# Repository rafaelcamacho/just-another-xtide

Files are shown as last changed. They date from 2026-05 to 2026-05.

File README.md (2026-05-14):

# Just Another XT-IDE

A collection of my XT-IDE PCB layout experiments and hardware variations
created for the retrocomputing community.

These boards are based on the original XT-IDE concepts and schematics from
GlitchWorks, with some PCB layout inspiration drawn from Monotech designs.

This repository provides:
- Gerber files
- Schematics
- Build notes and documentation

PCB source/layout files are intentionally not included.

Use at your risk.

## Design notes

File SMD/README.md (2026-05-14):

# SMD Just Another XT-IDE Boards

This directory contains SMD versions of the Just Another XT-IDE board designs.

The goal of these revisions is to provide:

- Routing fun.
- Low-cost final XT-IDE (...).

## Version Overview

| Version | Status | Notes |
|---|---|---|

## Design Philosophy

The SMD variants are intended for:

- Retro hardware experimentation.

## Notes

Each version directory contains:

- Gerber files.
- Bill of materials (BOM).
- Pick and Place file.
- Configuration documentation.

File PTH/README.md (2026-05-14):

# PTH Just Another XT-IDE Boards

This directory contains through-hole (PTH) versions of the Just Another XT-IDE board designs.

The goal of these revisions is to provide:

- Easy hand assembly.
- Component alignment.
- Switches access.
- Fix previous errors.

## Version Overview

| Version | Status | Notes |
|---|---|---|
| v0.4 | Prototype | Improved routing, mechanical adjustments and silkscreen |

## Design Philosophy

The PTH variants are intended for:

- Hobbyist assembly.
- Easier troubleshooting.
- Retro hardware experimentation.
- Low-cost PCB manufacturing.

## Notes

Each version directory contains:

- Gerber files.
- Bill of materials (BOM).
- Configuration documentation.

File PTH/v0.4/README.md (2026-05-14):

# Just Another XT-IDE PTH v0.4

## Documentation

| File | Description |
|---|---|
| SWITCHES.md | Jumper and switch configuration |
| BOM.md | Component list / Bill of Materials |

## Compatibility

Tested with:

- IBM XT compatible systems
- CompactFlash IDE adapters
- Standard IDE hard drives
- XTIDE Universal BIOS

## Notes

This board is intended for experimental and hobbyist retrocomputing use.

Some configurations may require BIOS changes depending on the target system.

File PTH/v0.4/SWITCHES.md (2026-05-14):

# Switch and Jumper Configuration

This document describes the configuration switches and jumpers available on the Just Another XT-IDE PTH v0.4 board.

---

## Switch Logic

| Value | State |
|---|---|
| 0 | OFF |
| 1 | ON |

---

# IDE Address

Default setting: `110000` (`0x300h`)

The IDE I/O base address is configured through switches 1 to 6.

| Switch | Address Bit |
|---|---|
| 1 | A9 |
| 2 | A8 |
| 3 | A7 |
| 4 | A6 |
| 5 | A5 |
| 6 | A4 |

---

## Address Table

| 1 | 2 | 3 | 4 | 5 | 6 | Address |
|---|---|---|---|---|---|---|
| 1 | 0 | 0 | 0 | 0 | 0 | 0200h |
| 1 | 0 | 0 | 0 | 0 | 1 | 0210h |
| 1 | 0 | 0 | 0 | 1 | 0 | 0220h |
| 1 | 0 | 0 | 0 | 1 | 1 | 0230h |
| 1 | 0 | 0 | 1 | 0 | 0 | 0240h |
| 1 | 0 | 0 | 1 | 0 | 1 | 0250h |
| 1 | 0 | 0 | 1 | 1 | 0 | 0260h |
| 1 | 0 | 0 | 1 | 1 | 1 | 0270h |
| 1 | 0 | 1 | 0 | 0 | 0 | 0280h |
| 1 | 0 | 1 | 0 | 0 | 1 | 0290h |
| 1 | 0 | 1 | 0 | 1 | 0 | 02A0h |
| 1 | 0 | 1 | 0 | 1 | 1 | 02B0h |
| 1 | 0 | 1 | 1 | 0 | 0 | 02C0h |
| 1 | 0 | 1 | 1 | 0 | 1 | 02D0h |
| 1 | 0 | 1 | 1 | 1 | 0 | 02E0h |
| 1 | 0 | 1 | 1 | 1 | 1 | 02F0h |
| 1 | 1 | 0 | 0 | 0 | 0 | 0300h |
| 1 | 1 | 0 | 0 | 0 | 1 | 0310h |
| 1 | 1 | 0 | 0 | 1 | 0 | 0320h |
| 1 | 1 | 0 | 0 | 1 | 1 | 0330h |
| 1 | 1 | 0 | 1 | 0 | 0 | 0340h |
| 1 | 1 | 0 | 1 | 0 | 1 | 0350h |
| 1 | 1 | 0 | 1 | 1 | 0 | 0360h |
| 1 | 1 | 0 | 1 | 1 | 1 | 0370h |
| 1 | 1 | 1 | 0 | 0 | 0 | 0380h |
| 1 | 1 | 1 | 0 | 0 | 1 | 0390h |
| 1 | 1 | 1 | 0 | 1 | 0 | 03A0h |
| 1 | 1 | 1 | 0 | 1 | 1 | 03B0h |
| 1 | 1 | 1 | 1 | 0 | 0 | 03C0h |
| 1 | 1 | 1 | 1 | 0 | 1 | 03D0h |
| 1 | 1 | 1 | 1 | 1 | 0 | 03E0h |
| 1 | 1 | 1 | 1 | 1 | 1 | 03F0h |

---

## Notes

- The most common XT-IDE address is `0300h`.
- Avoid conflicts with serial, parallel, network and sound cards.
- Some BIOS configurations may expect the controller at `0300h`.

---

# ROM Options

Default setting: `10001111` (`D0000h`,`32k`,`ROM Enabled`,`Writable`)

Switches 1 to 4 define the ROM base memory address.

| Switch | Address Bit |
|---|---|
| 1 | A16 |
| 2 | A15 |
| 3 | A14 |
| 4 | A13 |

---

## Address Table

| 1 | 2 | 3 | 4 | Address | ROM Support |
|---|---|---|---|---|---|
| 0 | 0 | 0 | 0 | C0000h | All |
| 0 | 0 | 0 | 1 | C2000h | 8k  |
| 0 | 0 | 1 | 0 | C4000h | 816k |
| 0 | 0 | 1 | 1 | C6000h | 8k |
| 0 | 1 | 0 | 0 | C8000h | All |
| 0 | 1 | 0 | 1 | CA000h | 8k |
| 0 | 1 | 1 | 0 | CC000h | 816k |
| 0 | 1 | 1 | 1 | CE000h | 8k |
| 1 | 0 | 0 | 0 | D0000h | All |
| 1 | 0 | 0 | 1 | D2000h | 8k |
| 1 | 0 | 1 | 0 | D4000h | 816k |
| 1 | 0 | 1 | 1 | D6000h | 8k |
| 1 | 1 | 0 | 0 | D8000h | All |
| 1 | 1 | 0 | 1 | DA000h | 8k |
| 1 | 1 | 1 | 0 | DC000h | 816k |
| 1 | 1 | 1 | 1 | DE000h | 8k |

---

## ROM Support Notes

| Description | Meaning |
|---|---|
| All | All ROM sizes, compatible with 8k, 16k and 32k ROMs |
| 8k | 8k only, valid only for 8k ROM configurations |
| 816k | Compatible with both 8k and 16k ROMs |

---

# ROM Size Selection

Switches 5 and 6 define the ROM size.

| 5 | 6 | ROM Size |
|---|---|---|
| 0 | 0 | 8k |
| 1 | 0 | 16k |
| 1 | 1 | 32k |

---

# ROM Control

Switches 7 and 8 control EEPROM enable and write protection.

| 7 | 8 | Function |
|---|---|---|
| EN | WR | EEPROM Enable / Write Control |

## Typical Settings

| EN | WR | Description |
|----|----|---|
| 0 | 0 | ROM disabled |
| 1 | 0 | ROM enabled, write protected |
| 1 | 1 | ROM enabled, write enabled |

---

## Notes

- `C8000h` and `D0000h` are the most common XT-IDE ROM addresses.
- Avoid ROM address conflicts with VGA, network and SCSI cards.
- Write enable should only be activated during EEPROM programming.
- 32k ROMs require aligned address ranges marked as "All ROM sizes".

---

# HiSpeed

The `HiSpeed` switch control the HiSpeed operating mode of the controller.

| HiSpeed | Mode |
|----|---|
| OFF | XT-IDE Rev1 Compatible mode |
| ON | XT-IDE Rev2 HiSpeed mode |

## Important

Changing the `HiSpeed` setting requires:

1. Reconfiguring the XTIDE Universal BIOS using `XTIDECFG.COM`, under Controller Type.
2. Reflashing the EEPROM with the updated BIOS image

Failure to update the BIOS configuration may prevent proper controller operation.

---

# IDE +5V Pin 20

A dedicated jumper allows +5V power to be supplied through pin 20 of the IDE connector.

## Usage

Enable this jumper when using:

- Disk-on-Module (DoM) devices.
- CompactFlash IDE adapters.
- Other IDE devices requiring power from pin 20.

Disable the jumper when using:

- Standard IDE hard drives with external power.
- Devices that do not expect +5V on pin 20.

---

# Operational Notes

## ROM Enable

Disable the ROM (`ROM Options`, switch 7 OFF) if the current ROM configuration prevents the system from booting.

For ROM reprogramming under DOS:

1. Boot the system with ROM disabled.
2. Enable switch 7 after the system is running.
3. Reflash the ROM.

Supported EEPROMs:

- 28C64
- 28C256

---

## ROM Write Protection

Disable ROM writes (`ROM Options`, switch 8 OFF) once the system is operating correctly.

This prevents accidental ROM overwrites.

---

## ROM Address Priority

Ensure the XT-IDE BIOS ROM address is located above any other boot ROMs installed in the system.

Otherwise:

- IDE drives may still be detected.
- Booting from those drives may fail.

---

## IDE Address Changes

Changing the IDE I/O address requires:

1. Reconfiguring the BIOS using `XTIDECFG.COM`.
2. Reflashing the ROM.

Changing only the ROM address does not require BIOS modification.

---

## IBM XT Slot 8 Usage

When using the board in slot 8 of an IBM XT system, verify the assembly instructions carefully.

Some IBM XT systems have slot-specific limitations and signal differences.

---

## IRQ Usage

IRQ is not used by XTIDE Universal BIOS versions released since October 2020.

The controller operates entirely in polling mode.

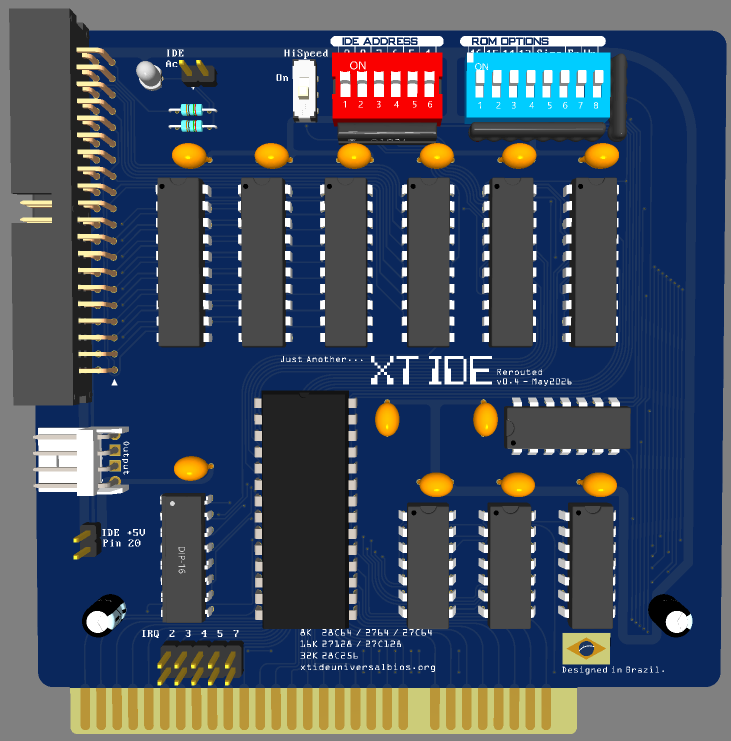
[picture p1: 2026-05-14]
PTH/v0.4/Images/Rendered.png

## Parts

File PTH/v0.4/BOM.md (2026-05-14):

# Bill of Materials (BOM)

## Integrated Circuits

| Reference | Quantity | Part |
|---|---|---|
| 573 | 2 | 74_753 |
| 245 | 2 | 74_245 |
| 688 | 2 | 74_688 |
| 138 | 1 | 74_138 |
| 04 | 2 | 74_04 |
| 32 | 1 | 74_32 |
| *33 | 1 | 74_33 |

*33 optional install if you need to enable Slot 8.

All 7400 series logic ICs `_` can be substituted for LS, ALS, ACT, or HCT equivalents.

---

## Capacitors

| Reference | Quantity | Part | Pitch |
|---|---|---|---|
| -||- | 12 | 100nF ceramic | 5.08mm |
| +||- | 2 | 100uF electrolytic | 2.00mm |

Voltages, at least, 16v.

---

## Resistors

| Reference | Quantity | Part |
|---|---|---|
|  | 2 | 490R for LED´s |
|  | 1 | 10K resistor array 8 pin |
|  | 1 | 10K resistor array 6 pin |
|  | 1 | 10K resistor array 5 pin |

---

## Switches and Jumpers

| Reference | Part |
|---|---|
| Switch HiSpeed | MSS22D18 Mini Miniature DIP Slide Switch 2P2T 6Pin |
| IDE Address | Slide Type Switch Module 2.54mm 6-Bit 6 Position Way |
| ROM Options | Slide Type Switch Module 2.54mm 8-Bit 8 Position Way |
| LED and IDE 5V | 2.54mm Pin Header Breakable |
| IDE | Connector IDC Header Through Hole, Right Angle 40 position 2.54mm |

---

# Notes

- Socketed ICs are recommended.

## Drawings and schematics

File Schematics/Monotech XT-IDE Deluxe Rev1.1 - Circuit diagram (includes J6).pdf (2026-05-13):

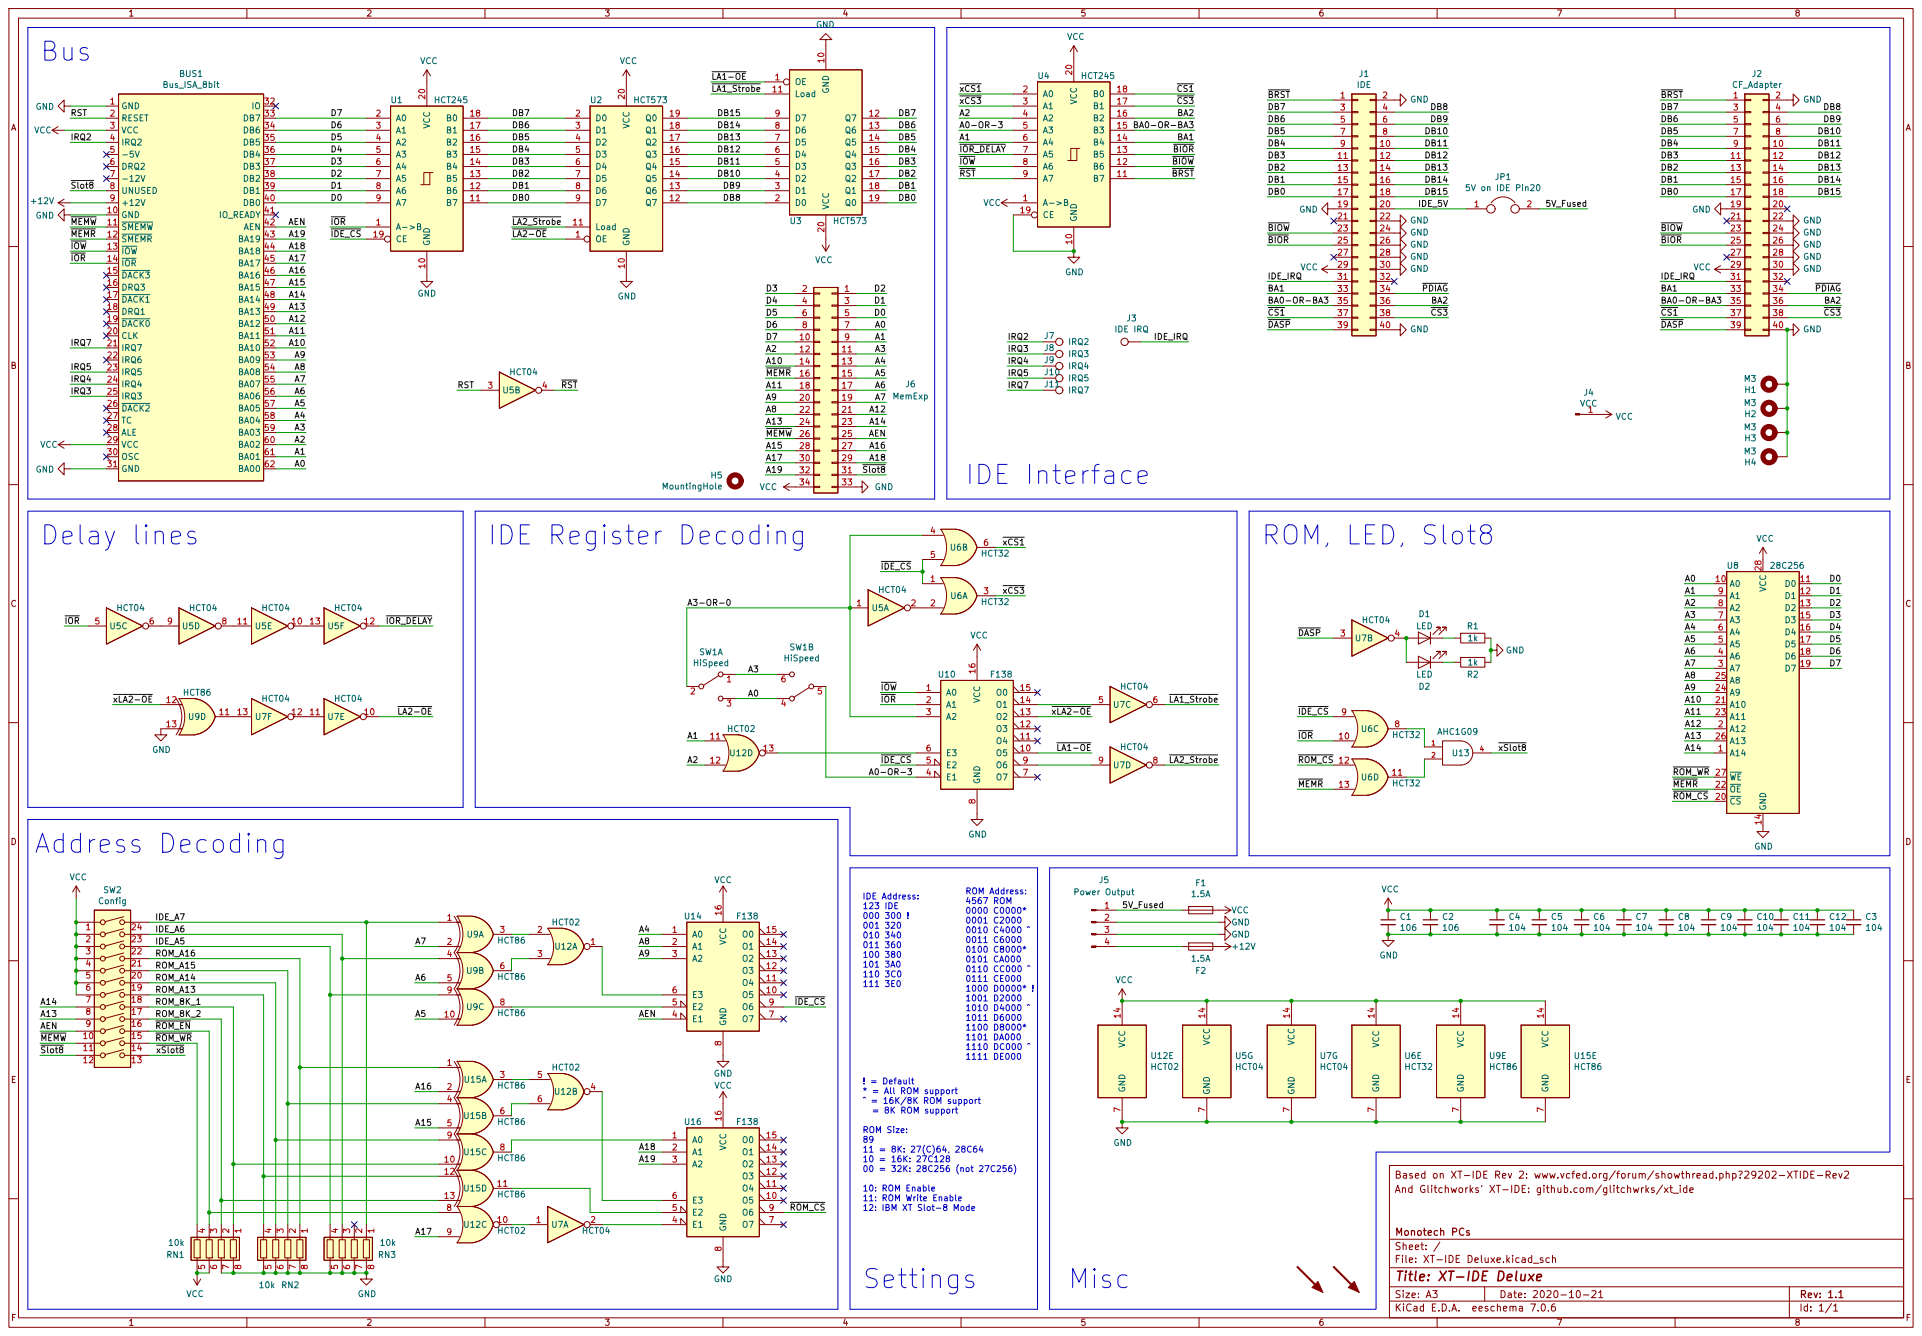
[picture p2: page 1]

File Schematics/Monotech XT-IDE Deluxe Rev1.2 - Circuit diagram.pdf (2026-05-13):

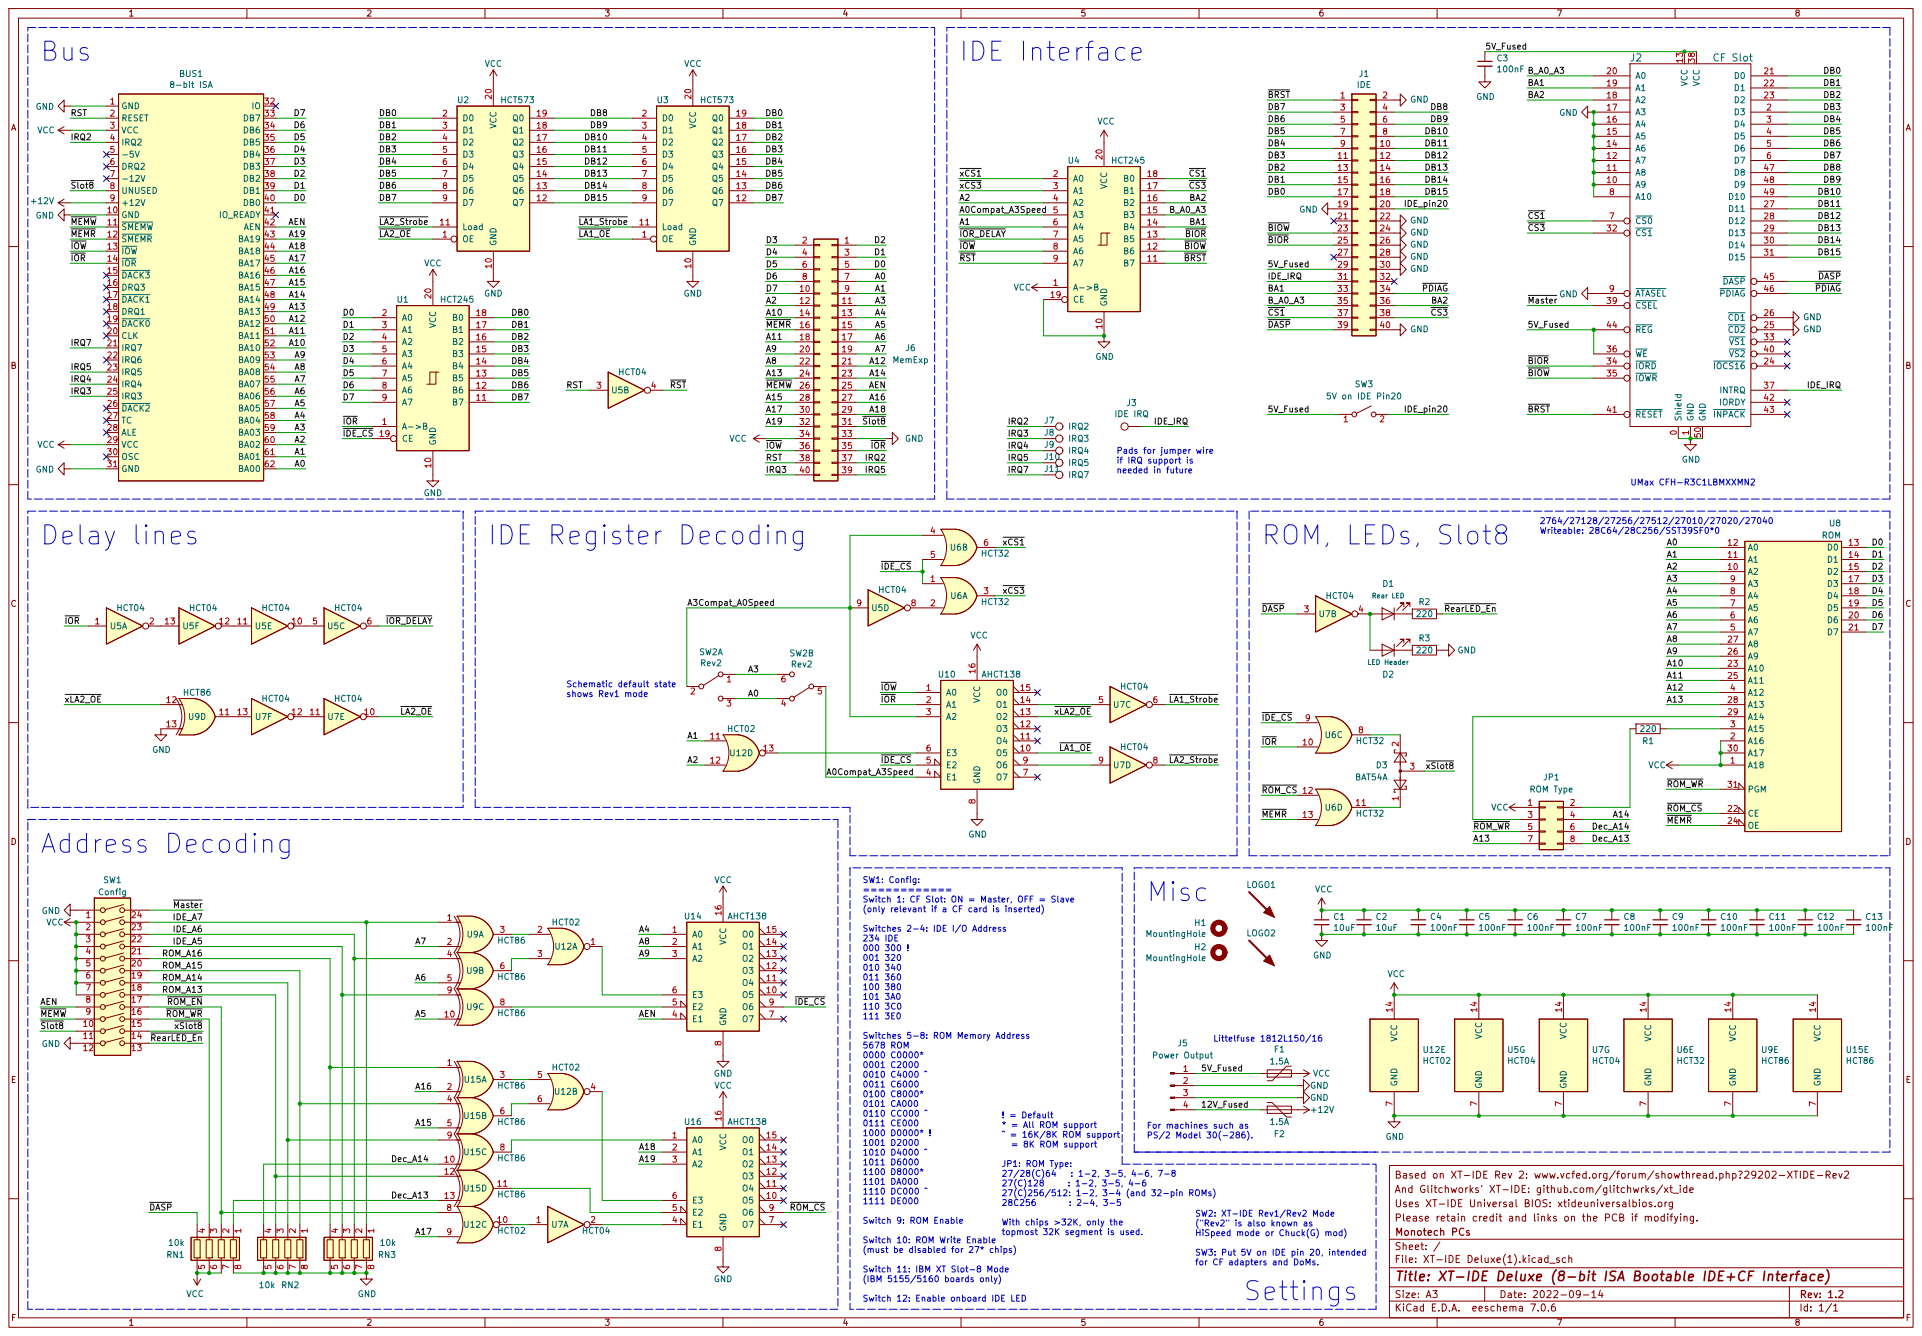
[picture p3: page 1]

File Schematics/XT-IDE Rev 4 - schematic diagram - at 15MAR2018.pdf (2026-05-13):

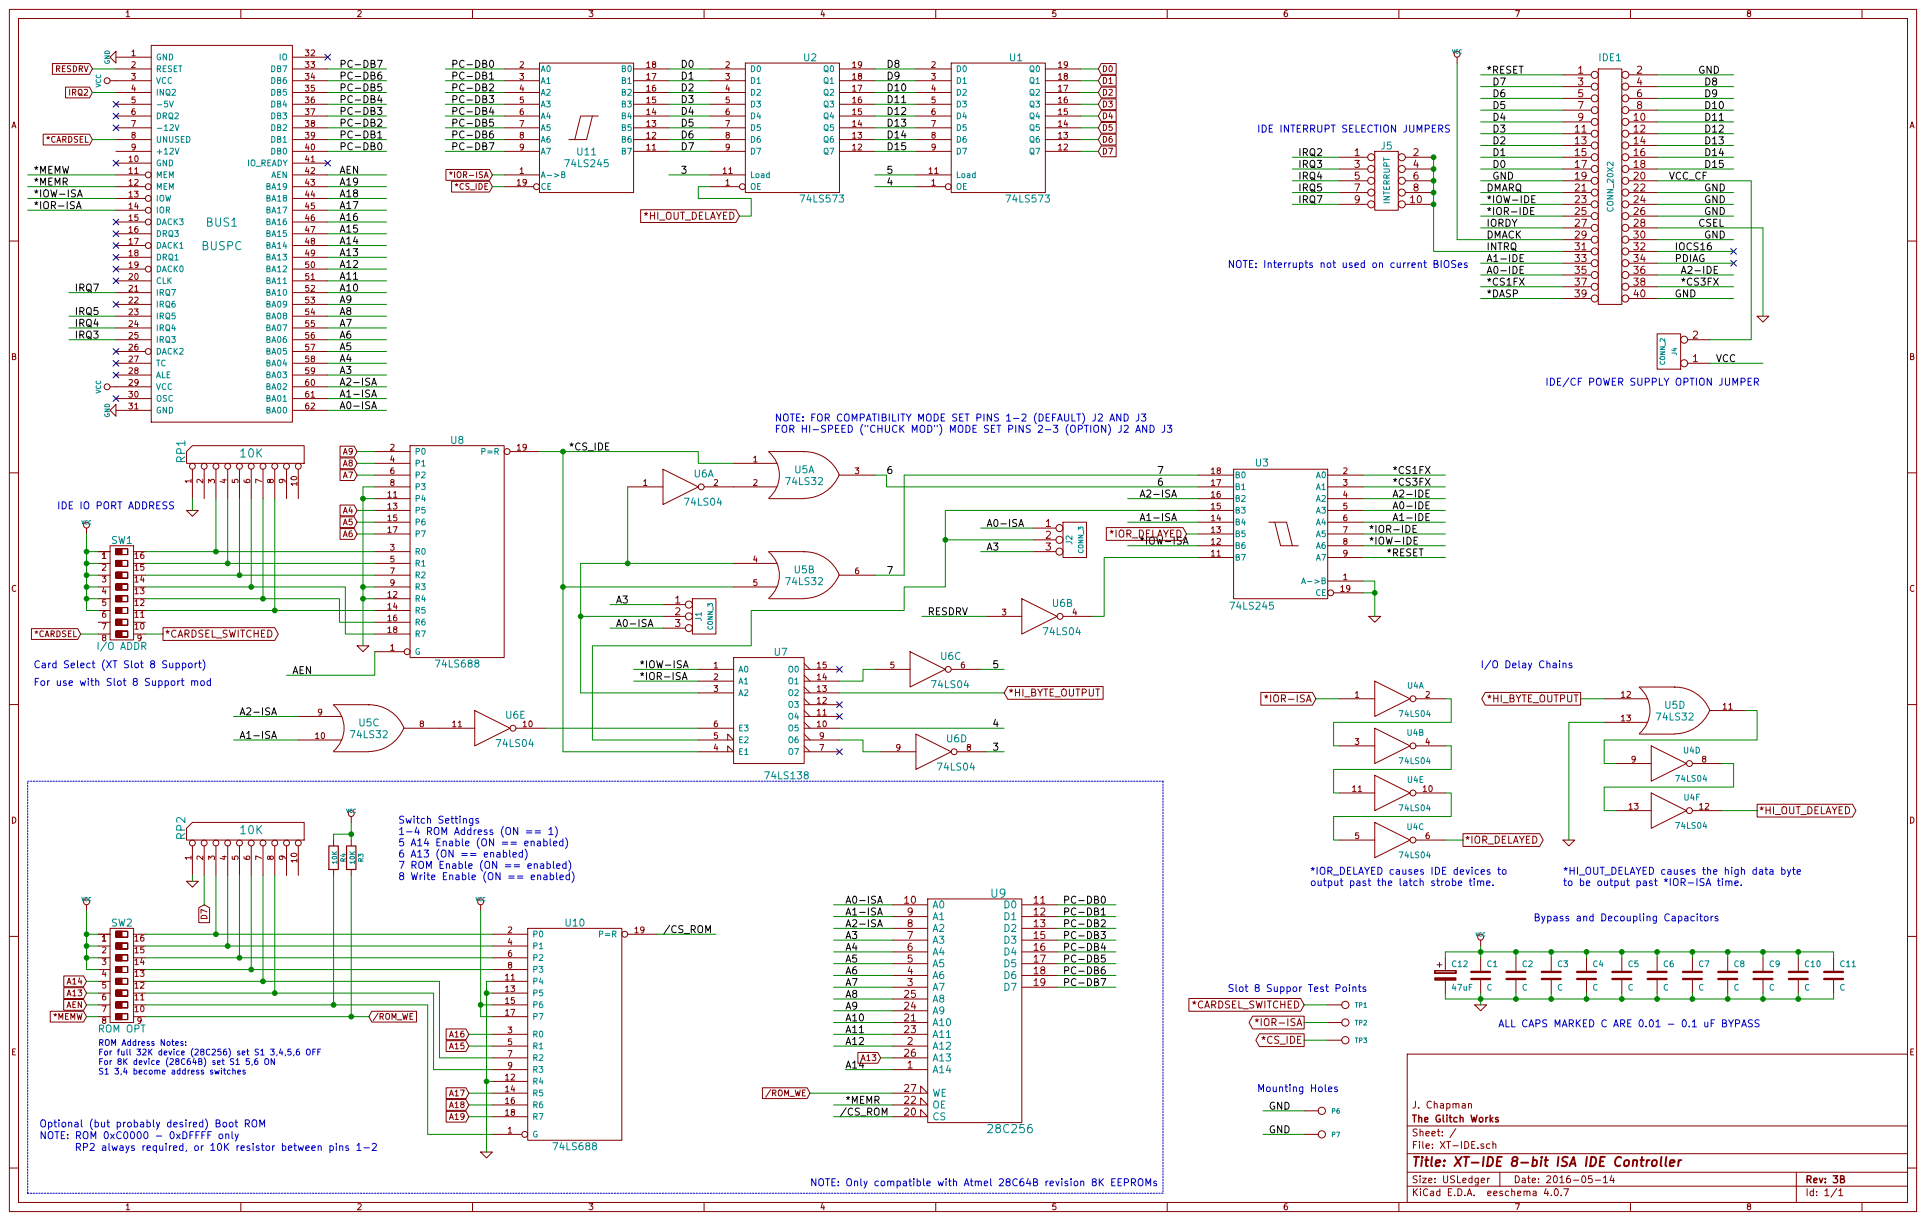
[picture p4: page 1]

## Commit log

2026-05-14 Create README.md for PTH XT-IDE Boards
    Added README.md for PTH XT-IDE Boards with project details.
2026-05-14 Add SWITCHES.md for XT-IDE PTH v0.4 configuration
    This document provides detailed information on the configuration switches and jumpers for the Just Another XT-IDE PTH v0.4 board, including IDE address settings, ROM options, and operational notes.
2026-05-14 Create BOM.md for project components
    Added a comprehensive Bill of Materials (BOM) detailing integrated circuits, capacitors, resistors, switches, and jumpers.
2026-05-14 Rename project from 'PTH XT-IDE Boards' to 'PTH Just Another XT-IDE Boards'
2026-05-14 Add README.md for SMD XT-IDE board designs
